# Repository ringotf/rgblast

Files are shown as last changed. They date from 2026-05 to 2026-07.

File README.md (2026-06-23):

# RGBlast - RGB + Audio To HDMI For Sega Master System & Genesis/Mega Drive

- Master System : (See "sms" branch) - Work in progress! 
- Genesis/Mega Drive : (See "md" branch)  - Work in progress! 

## Description

The original RGBlast project was a 2-bit flash analog-to-digital converter RP2040-based video capture for the Sega Mega-Drive/Genesis... which is ideal for capturing the RGB222 video signals from the Sega Master System!

This prototype has been updated so that instead of using 9 comparators (3 per RGB channel), the channels are multiplexed and switched mid-pixel for sampling so only 3 comparators are used with 3 SPDT analog switches.

## Features

- RGB222 Video Capture
- Mono Audio Capture
- HDMI output using [ikjordan PicoDVI fork](https://github.com/ikjordan/picodvi)

## To-Do

- Update schematics
- Fix wobbly vertical lines
- 50/60hz switch?
- Design PCB
- ???

## Demo Video

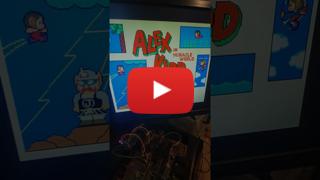
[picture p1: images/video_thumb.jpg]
[](https://youtube.com/shorts/fzoDApS1l0w)

----
----

Original Readme:

# SEGA Genesis RGBlast Processor - RP2040 code & Schematics

A hardware design for capturing RGB direct from a SEGA Genesis and delivering it via USB to a PC.

## Description

The SEGA Genesis RGBlast Processor is a Raspi Pico based video capture device that directly digitizes the RGB output of a SEGA Genesis and delivers it via USB to a host computer.

The analog channels (RGB) are captured via a 2 bit Flash ADC which is half hardware and half PIO program.

To build a functioning version from scratch, please see the circuit-schematics folder. PCB Schematics will be released if/when a proven design is achieved. Here is one of the latest prototypes as built from the schematic:



At the moment this device is capable of 6 bits per pixel, ~30FPS. Video is fairly noisy in the test PCBs which have been constructed:

https://user-images.githubusercontent.com/127321359/224463316-a748747a-c26d-4245-b84a-755739763bbe.mp4

## Getting Started

Building this to a Raspi Pico requires the C/C++ SDK: https://www.raspberrypi.com/documentation/microcontrollers/c_sdk.html

It is possible to test this device with more commonly available parts. For example utilizing LM393s as comparators (rather than the MCP6569) on a breadboard will work, but the image will be very noisy/sloppy.

You could also utilize the Raspi Pico's built-in USB (instead of the FTDI external device.) Framerates will be significantly lower.

Please see the Rust client project for the software which can receive and decode the incoming 6bpp stream to a simple application window.

## Authors

Contributors names and contact info

JP Stringham
[@jotapeh](https://mastodon.gamedev.place/@jotapeh)

## Version History

* 0.1
    * Initial Release

## License

This project is licensed under the MIT License - see the LICENSE file for details

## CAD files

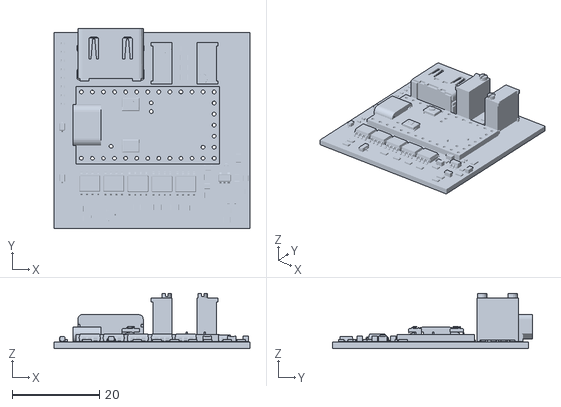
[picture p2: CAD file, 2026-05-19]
hw/rgblast-sms-test.stl
45.0 x 46.0 x 12.7

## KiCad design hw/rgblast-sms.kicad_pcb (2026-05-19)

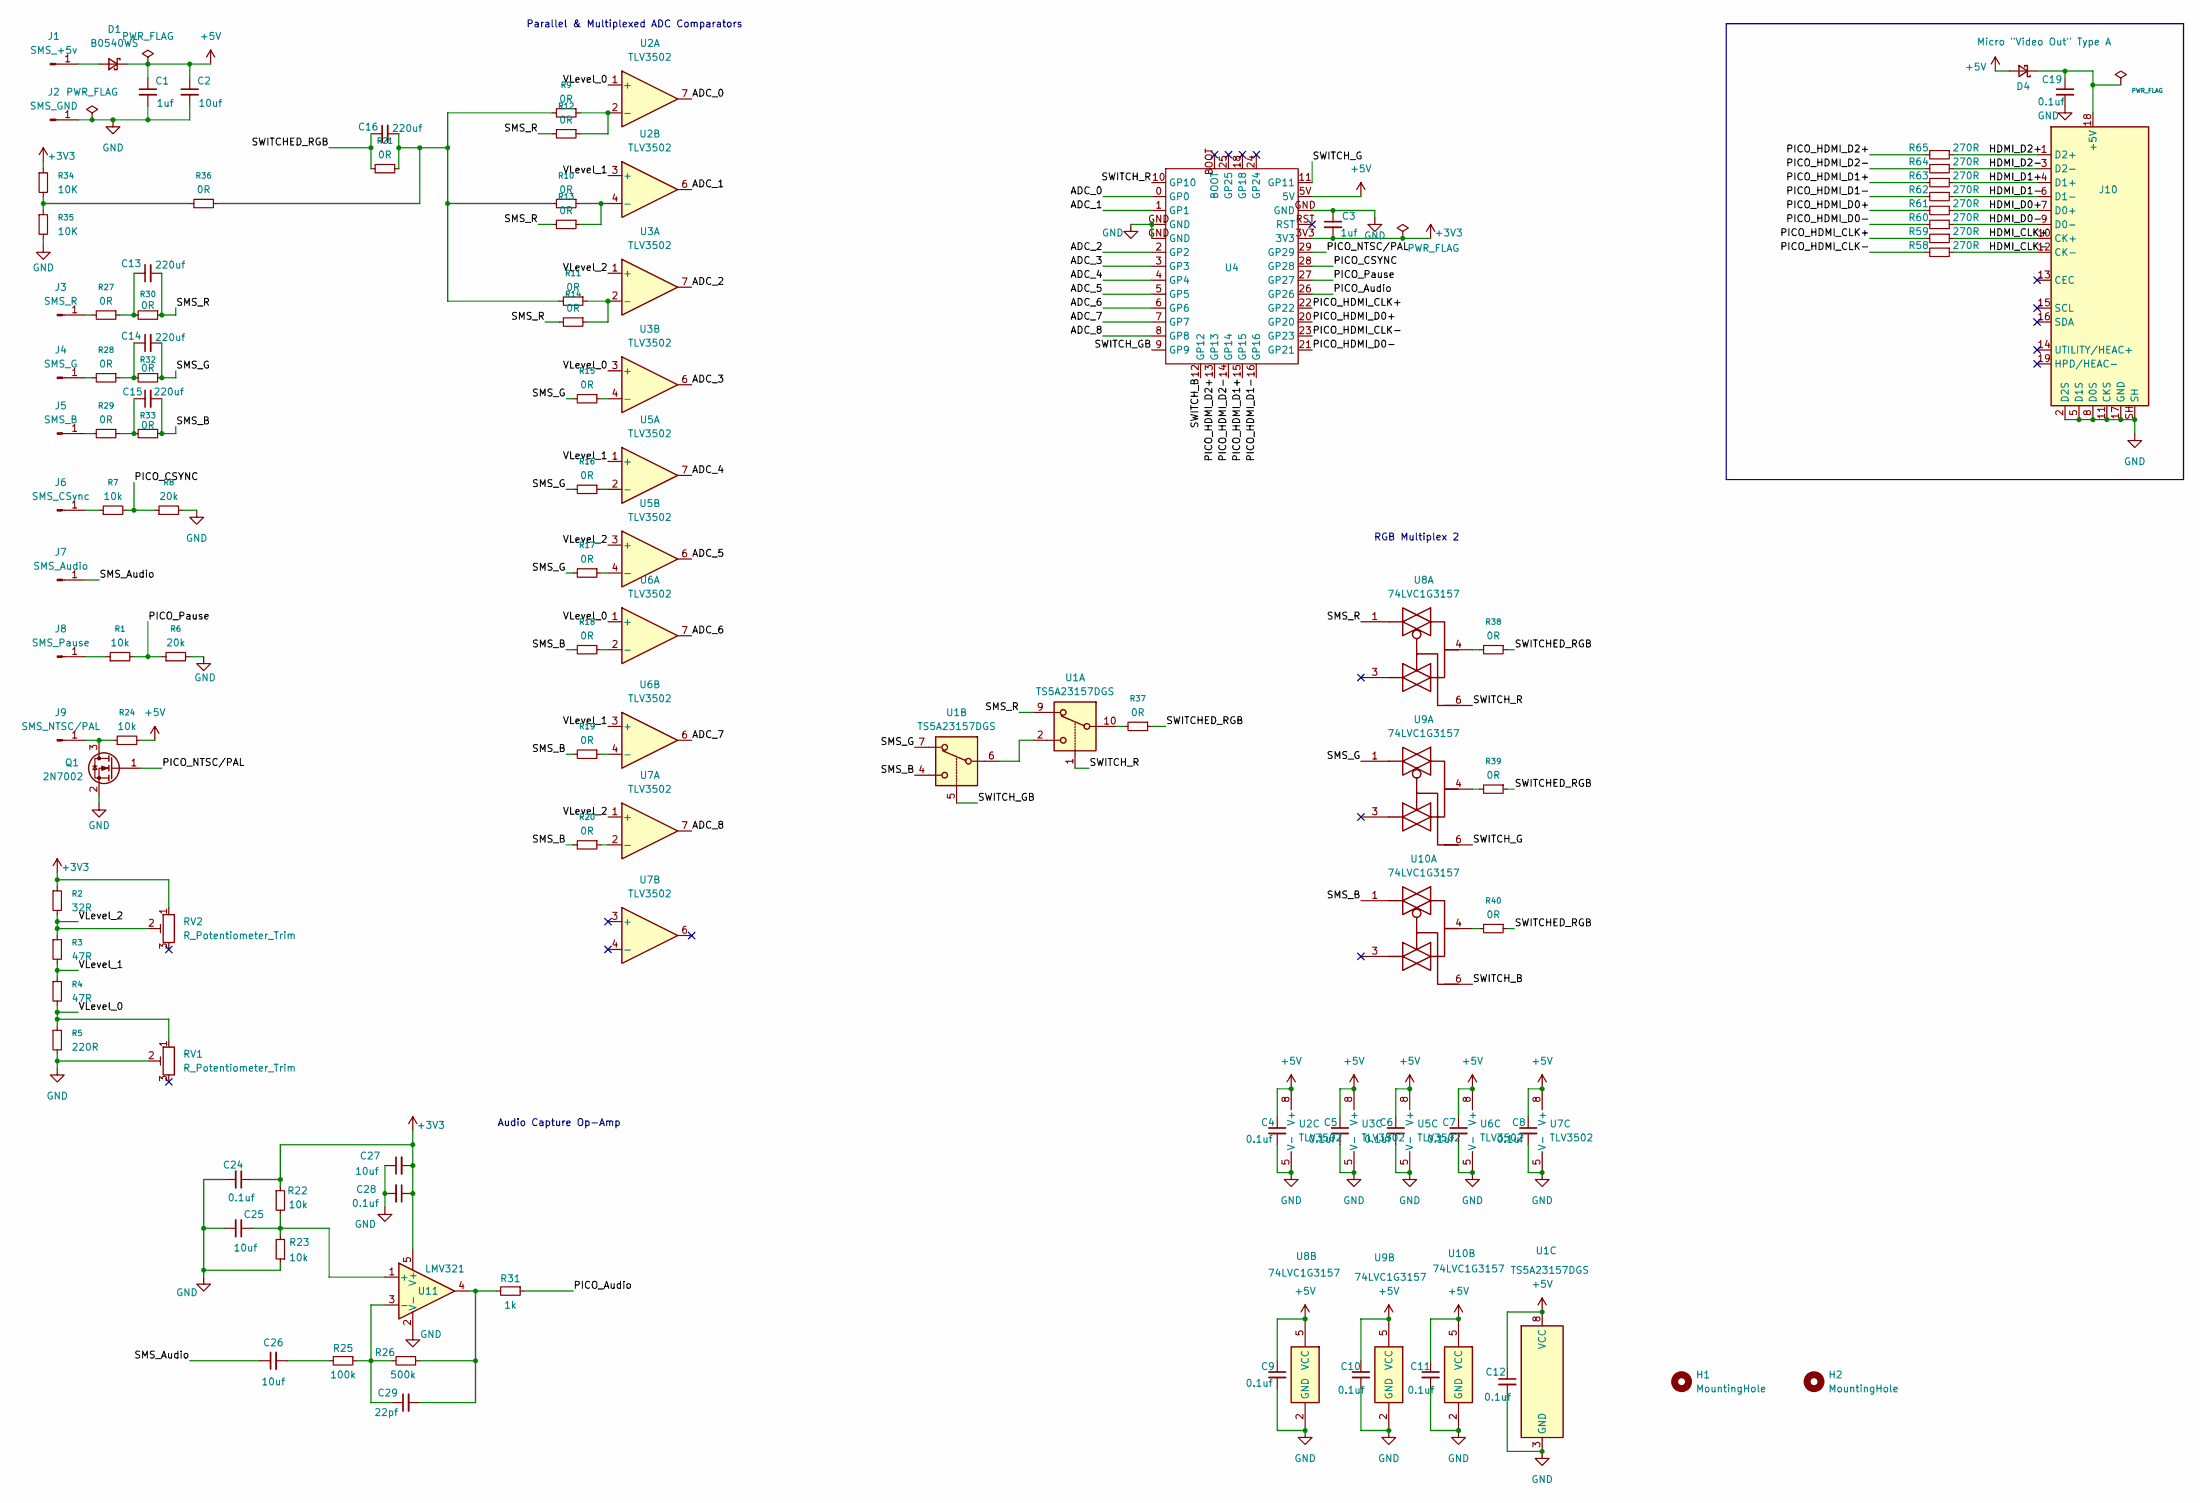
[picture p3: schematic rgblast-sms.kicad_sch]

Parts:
C1, C3: 1uf; C_0402_1005Metric_Pad0.74x0.62mm_HandSolder
C2, C27: 10uf; C_0402_1005Metric_Pad0.74x0.62mm_HandSolder
C4, C5, C6, C7, C8, C9, C10, C11, C12, C19, C28: 0.1uf; C_0402_1005Metric_Pad0.74x0.62mm_HandSolder
C13, C14, C15, C16: 220uf; C_0805_2012Metric_Pad1.18x1.45mm_HandSolder
C24: 0.1uf; C_0805_2012Metric_Pad1.18x1.45mm_HandSolder
C25, C26: 10uf; C_0805_2012Metric_Pad1.18x1.45mm_HandSolder
C29: 22pf; C_0805_2012Metric_Pad1.18x1.45mm_HandSolder
D1, D4: B0540WS; D_SOD-323_HandSoldering
H1, H2: MountingHole; ToolingHole_1.152mm
J1: SMS_+5v; TestPoint_Pad_D1.0mm
J2: SMS_GND; TestPoint_Pad_D1.0mm
J3: SMS_R; TestPoint_Pad_D1.0mm
J4: SMS_G; TestPoint_Pad_D1.0mm
J5: SMS_B; TestPoint_Pad_D1.0mm
J6: SMS_CSync; TestPoint_Pad_D1.0mm
J7: SMS_Audio; TestPoint_Pad_D1.0mm
J8: SMS_Pause; TestPoint_Pad_D1.0mm
J9: SMS_NTSC/PAL; TestPoint_Pad_D1.0mm
J10: Micro "Video Out" Type A; HDMI_A_Molex_208658-1001_Horizontal
Q1: 2N7002; SOT-23
R1, R7, R22, R23, R24: 10k; R_0805_2012Metric_Pad1.20x1.40mm_HandSolder
R2: 32R; R_0805_2012Metric_Pad1.20x1.40mm_HandSolder
R3, R4: 47R; R_0805_2012Metric_Pad1.20x1.40mm_HandSolder
R5: 220R; R_0805_2012Metric_Pad1.20x1.40mm_HandSolder
R6, R8: 20k; R_0805_2012Metric_Pad1.20x1.40mm_HandSolder
R9, R10, R11, R12, R13, R14, R15, R16, R17, R18, R19, R20, R21, R27, R28, R29, R30, R32, R33, R36, R37, R38, R39, R40: 0R; R_0805_2012Metric_Pad1.20x1.40mm_HandSolder
R25: 100k; R_0805_2012Metric_Pad1.20x1.40mm_HandSolder
R26: 500k; R_0805_2012Metric_Pad1.20x1.40mm_HandSolder
R31: 1k; R_0805_2012Metric_Pad1.20x1.40mm_HandSolder
R34, R35: 10K; R_0805_2012Metric_Pad1.20x1.40mm_HandSolder
R58, R59, R60, R61, R62, R63, R64, R65: 270R; R_0402_1005Metric_Pad0.72x0.64mm_HandSolder
RV1, RV2: R_Potentiometer_Trim; Potentiometer_Bourns_3296W_Vertical
U1: TS5A23157DGS; TSSOP-10_3x3mm_P0.5mm
U2, U3, U5, U6, U7: TLV3502; SOIC-8_3.9x4.9mm_P1.27mm
U4: pro_micro_rp2040
U8, U9, U10: 74LVC1G3157; SOT-23-6_Handsoldering
U11: LMV321; SOT-23-5_HandSoldering

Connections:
+3V3: C3.2, C24.1, C27.2, C28.1, R2.1, R22.1, R34.1, RV2.1, U4.3V3, U11.5 (V+)
+5V: C1.1, C2.1, C4.1, C5.1, C6.1, C7.1, C8.1, C9.1, C10.1, C11.1, C12.1, D1.1 (K), D4.2 (A), R24.2, U1.8 (VCC), U2.8 (V+), U3.8 (V+), U4.5V, U5.8 (V+), U6.8 (V+), U7.8 (V+), U8.5 (VCC), U9.5 (VCC), U10.5 (VCC)
/ADC_0: U2.7, U4.0 (GP0)
/ADC_1: U2.6, U4.1 (GP1)
/ADC_2: U3.7, U4.2 (GP2)
/ADC_3: U3.6, U4.3 (GP3)
/ADC_4: U4.4 (GP4), U5.7
/ADC_5: U4.5 (GP5), U5.6
/ADC_6: U4.6 (GP6), U6.7
/ADC_7: U4.7 (GP7), U6.6
/ADC_8: U4.8 (GP8), U7.7
/HDMI_CLK+: J10.10 (CK+), R59.1
/HDMI_CLK-: J10.12 (CK-), R58.1
/HDMI_D0+: J10.7 (D0+), R61.1
/HDMI_D0-: J10.9 (D0-), R60.1
/HDMI_D1+: J10.4 (D1+), R63.1
/HDMI_D1-: J10.6 (D1-), R62.1
/HDMI_D2+: J10.1 (D2+), R65.1
/HDMI_D2-: J10.3 (D2-), R64.1
/PICO_Audio: R31.1, U4.26 (GP26)
/PICO_CSYNC: R7.2, R8.1, U4.28 (GP28)
/PICO_HDMI_CLK+: R59.2, U4.22 (GP22)
/PICO_HDMI_CLK-: R58.2, U4.23 (GP23)
/PICO_HDMI_D0+: R61.2, U4.20 (GP20)
/PICO_HDMI_D0-: R60.2, U4.21 (GP21)
/PICO_HDMI_D1+: R63.2, U4.15 (GP15)
/PICO_HDMI_D1-: R62.2, U4.16 (GP16)
/PICO_HDMI_D2+: R65.2, U4.13 (GP13)
/PICO_HDMI_D2-: R64.2, U4.14 (GP14)
/PICO_NTSC/PAL: Q1.1 (G), U4.29 (GP29)
/PICO_Pause: R1.2, R6.1, U4.27 (GP27)
/SMS_Audio: C26.1, J7.1 (Pin_1_1)
/SMS_B: C15.2, R18.2, R19.2, R20.2, R33.1, U1.4, U10.1
/SMS_G: C14.2, R15.2, R16.2, R17.2, R32.1, U1.7, U9.1
/SMS_R: C13.2, R12.2, R13.2, R14.2, R30.1, U1.9, U8.1
/SWITCHED_RGB: C16.1, R21.2, R37.1, R38.1, R39.1, R40.1
/SWITCH_B: U4.12 (GP12), U10.6
/SWITCH_G: U4.11 (GP11), U9.6
/SWITCH_GB: U1.5, U4.9 (GP9)
/SWITCH_R: U1.1, U4.10 (GP10), U8.6
/VLevel_0: R4.2, R5.1, RV1.1, U2.1 (+), U3.3 (+), U6.1 (+)
/VLevel_1: R3.2, R4.1, U2.3 (+), U5.1 (+), U6.3 (+)
/VLevel_2: R2.2, R3.1, RV2.2, U3.1 (+), U5.3 (+), U7.1 (+)
GND: C1.2, C2.2, C3.1, C4.2, C5.2, C6.2, C7.2, C8.2, C9.2, C10.2, C11.2, C12.2, C19.2, C24.2, C25.2, C27.1, C28.2, J2.1 (Pin_1_1), J10.2 (D2S), J10.5 (D1S), J10.8 (D0S), J10.11 (CKS), J10.17 (GND), J10.SH, Q1.2 (S), R5.2, R6.2, R8.2, R23.1, R35.2, RV1.2, U1.3 (GND), U2.5 (V-), U3.5 (V-), U4.GND, U5.5 (V-), U6.5 (V-), U7.5 (V-), U8.2 (GND), U9.2 (GND), U10.2 (GND), U11.2 (V-)
unnamed: C13.1, R27.1, R30.2
unnamed: C14.1, R28.1, R32.2
unnamed: C15.1, R29.1, R33.2
unnamed: C16.2, R9.2, R10.2, R11.2, R21.1, R36.1
unnamed: C26.2, R25.2
unnamed: C29.2, R26.1, R31.2, U11.4
unnamed: D1.2 (A), J1.1 (Pin_1_1)
unnamed: C19.1, D4.1 (K), J10.18 (+5V)
unnamed: J3.1 (Pin_1_1), R27.2
unnamed: J4.1 (Pin_1_1), R28.2
unnamed: J5.1 (Pin_1_1), R29.2
unnamed: J6.1 (Pin_1_1), R7.1
unnamed: J8.1 (Pin_1_1), R1.1
unnamed: J9.1 (Pin_1_1), Q1.3 (D), R24.1
unnamed: R34.2, R35.1, R36.2
unnamed: R37.2, U1.10
unnamed: R38.2, U8.4
unnamed: R39.2, U9.4
unnamed: R40.2, U10.4
unnamed: U1.2, U1.6
unnamed: R9.1, R12.1, U2.2 (-)
unnamed: R10.1, R13.1, U2.4 (-)
unnamed: R11.1, R14.1, U3.2 (-)
unnamed: R15.1, U3.4 (-)
unnamed: R16.1, U5.2 (-)
unnamed: R17.1, U5.4 (-)
unnamed: R18.1, U6.2 (-)
unnamed: R19.1, U6.4 (-)
unnamed: R20.1, U7.2 (-)
unnamed: C25.1, R22.2, R23.2, U11.1 (+)
unnamed: C29.1, R25.1, R26.2, U11.3 (-)

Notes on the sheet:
RGB Multiplex 2
Parallel & Multiplexed ADC Comparators
Audio Capture Op-Amp

Board: 2 copper layers, 97 parts (0 on the bottom side), 75 nets, no tracks yet.

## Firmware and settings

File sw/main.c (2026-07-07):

#include <stdio.h>
#include <string.h>

#include <stdlib.h>
#include "pico/stdlib.h"
#include "pico/multicore.h"
#include "pico/time.h"
#include "pico/flash.h"

#include "hardware/adc.h"
#include "hardware/pio.h"
#include "hardware/dma.h"
#include "hardware/vreg.h"
#include "hardware/clocks.h"
#include "hardware/flash.h"

#include "vsync_detector.pio.h"
#include "pio_6bpp_color_read.pio.h"
//#include "flash_adc.pio.h"

#include "libdvi/dvi.h"
#include "libdvi/dvi_serialiser.h"
#include "libdvi/dvi_timing.h"

#include "main.h"

/*
#include "pico/mutex.h"
static mutex_t printf_mutex;

void safe_printf(const char* format, ...)
{
    va_list args;
    va_start(args, format);
    
    mutex_enter_blocking(&printf_mutex);
    vprintf(format, args);
    //printf(format, args);
    mutex_exit(&printf_mutex);
    
    va_end(args);
}
*/


#include "pico/util/queue.h"

#define LOG_QUEUE_LENGTH 16

typedef struct {
    char msg[80];
} log_entry_t;

static queue_t log_queue;

/*
// ====================== Initialization (on Core 0) ======================
void init_logging(void) {
    queue_init(&log_queue, sizeof(log_entry_t), LOG_QUEUE_LENGTH);
}


// ====================== Safe logging from Core 1 ======================
void log_from_core1(const char* format, ...) {
    log_entry_t entry;
    va_list args;
    va_start(args, format);
    vsnprintf(entry.msg, sizeof(entry.msg), format, args);
    va_end(args);
    
    queue_try_add(&log_queue, &entry);   // non-blocking
}

// ====================== Process logs on Core 0 (in main loop) ======================
void process_logs(void) {
    log_entry_t entry;
    while (queue_try_remove(&log_queue, &entry)) {
        printf("%s", entry.msg);
        stdio_flush();        // optional but helpful
    }
}
*/

#define IMAGE_SIZE_PIXELS (pixels_in_scanline*scanlines_in_active_area)
#define PIXELS_PER_WORD 1 //5 // 5px*6bpp+2bits
#define IMAGE_SIZE_WORDS (IMAGE_SIZE_PIXELS/PIXELS_PER_WORD)
#define IMAGE_SIZE_BYTES (IMAGE_SIZE_WORDS) //(IMAGE_SIZE_WORDS*4)


PIO vidPIO = pio0;
uint sm_sync = 0;
uint sm_read = 1;
//uint sm_read_line = 2;
uint sm_read_pixel = 2; //3;


uint offset_sync_program;
uint offset_read_program;
//uint offset_read_line_program;
uint offset_read_pixel_program;

//uint32_t IMAGE_DATA[IMAGE_SIZE_WORDS+1];
unsigned char IMAGE_DATA[IMAGE_SIZE_WORDS];
unsigned char * IMAGE_DATA_ADDRESS = IMAGE_DATA;

int dma_chan_capture;
int dma_chan_reset;

int dma_chan_lookup_capture;
int dma_chan_write_capture;
int dma_chan_lookup_reset;
int dma_chan_write_reset;


bool frameReady;

//PIO adcPIO = pio0; //pio1;
//uint sm_flashadc_red = 0;

// sync reading
// const uint SYNC_OUT_PIN = 22; // this will have to be disabled with FTDI, not enough pins
const uint SYNC_IN_PIN = 27; //15;

// pixel reading
// const uint RGB_IN_STATUS_OUT_PIN = 28;  // this will have to be disabled with FTDI, not enough pins
//const uint RGB_IN_START_PIN = 6; //9; // 9 10 b, 11 12 g, 13 14 r

//const uint BLUE_ADC_IN_PIN = 27; //16; // 16, 17, 18
//const uint BLUE_ADC_OUT_PIN = 6; //9;

//const uint GREEN_ADC_IN_PIN = 20; //19; // 19, 20, 21
//const uint GREEN_ADC_OUT_PIN = 8; //11;

const uint RED_ADC_IN_PIN = 0; //26; // 26, 27, 28
//const uint RED_ADC_OUT_PIN = 10; //13;

/*
const uint RED_NOT_ENABLE_PIN = 20;
const uint GREEN_NOT_ENABLE_PIN = 21;
const uint BLUE_NOT_ENABLE_PIN = 22;
*/
const uint ADC_PIN_COUNT = 3;

const uint NTSC_PAL_PIN = 28;
const uint PAUSE_PIN = 29;



const uint SWITCH_DRAIN_PIN = 4;

const uint SWITCH_R_PIN = 9;
const uint SWITCH_GB_PIN = 10;
const uint SWITCH_G_PIN = 10;
const uint SWITCH_B_PIN = 11;




const uint USER_BTN_PIN = 24;

#define VDP_NTSC_MODE 1
#define VDP_PAL_MODE 0


//libdvi output
#define dvi_d2_pins_base 22
#define dvi_d1_pins_base 20
#define dvi_d0_pins_base 13
#define dvi_clk_pins_base 15

//
//libdvi config
//

#define dvi_pio pio1
#define dvi_tmds_sm_0 1
#define dvi_tmds_sm_1 2
#define dvi_tmds_sm_2 3

// DVDD 1.2V (1.1V seems ok too)
//#define FRAME_WIDTH 320
//#define FRAME_HEIGHT 240
#define VREG_VSEL VREG_VOLTAGE_1_20

#define DVI_TIMING dvi_timing_640x480p_60hz

struct dvi_inst dvi0;

static struct dvi_serialiser_cfg pico_sms_rgb_conf = {
	.pio = dvi_pio,
	.sm_tmds = {dvi_tmds_sm_0, dvi_tmds_sm_1, dvi_tmds_sm_2},
	.pins_tmds = {dvi_d0_pins_base, dvi_d1_pins_base, dvi_d2_pins_base},
	.pins_clk = dvi_clk_pins_base,
	.invert_diffpairs = false
};

#define DVI_DMA_IRQ DMA_IRQ_0

#define DVI_AUDIO_CTS 28000
#define DVI_AUDIO_BUFFER_SIZE 256
audio_sample_t dvi_audio_buffer[DVI_AUDIO_BUFFER_SIZE];


//
//ADC audio capture
//
#define AUDIO_SAMPLE_RATE 44100
#define AUDIO_CHANNEL_COUNT 1 //4 //2 audio + 1 brightness potentiometer, but needs to be power of 2 for dma and ring buffer to work ok 
#define AUDIO_BUFFER_BITS 8 //11
#define AUDIO_BUFFER_SIZE (1 << AUDIO_BUFFER_BITS)
//#define AUDIO_BUFFER_SIZE 1024

__attribute__((aligned((1 << AUDIO_BUFFER_BITS))))
__attribute__((section(".time_critical.ram")))
static uint16_t audio_buffer[AUDIO_BUFFER_SIZE];

static const uint32_t audio_buffer_addr = (uint32_t)audio_buffer;




__attribute__((aligned(0x8)))
 unsigned char TWO_BIT_LUT[8] = {
    0b00,
    0b01,
    0b10,
    0b10,
    0b11,
    0b11,
    0b11,
    0b11
};

__attribute__((aligned(0x8)))
 unsigned char TWO_BIT_LUT_INVERTED[8] = {

    0b11,
    0b10,
    0b01,
    0b01,
    0b00,
    0b00,
    0b00,
    0b00

};

__attribute__((aligned(0x8)))
 unsigned char ONE_BIT_LUT[8] = {
    0b00,
    0b10,
    0b10,
    0b11,
};

__attribute__((aligned(0x200)))
unsigned char SIX_BIT_LUT[512];


void generate_lut()
{
    printf("%s: Generating Lut...\n", __func__);

    for(uint16_t r = 0; r < 8; r++)
    { 
        for(uint16_t g = 0; g < 8; g++)
        {
            for(uint16_t b = 0; b < 8; b++)
            {

                uint16_t r_value = TWO_BIT_LUT[r];
                uint16_t g_value = TWO_BIT_LUT[g];
                uint16_t b_value = TWO_BIT_LUT[b];

                //uint16_t r_value = TWO_BIT_LUT_INVERTED[r];
                //uint16_t g_value = TWO_BIT_LUT_INVERTED[g];
                //uint16_t b_value = TWO_BIT_LUT_INVERTED[b];

                
                uint16_t lut_value = (r_value << 4) | (g_value << 2) | (b_value);

                uint16_t lut_index = (r * 64) + (g * 8) + b;
                SIX_BIT_LUT[lut_index] = lut_value;

                
                //printf("R: %d G: %d B: %d Index: %04X %012b, Value: %04X %06b\n", r, g, b, lut_index, lut_index, lut_value, lut_value);

            }
        }
    }

}



//
//draws a pattern of colour bars vertically with varying intensity horizontally
//fills the frame buffer which is larger than the lcd, appears clipped in the output is normal
//
void fill_framebuffer_with_test_pattern() {
	uint16_t test_divs = pixels_in_scanline / 8;	
	uint16_t row_size = scanlines_in_active_area / 3;
	uint16_t row_diff = 1;

	for(uint32_t y = 0; y < scanlines_in_active_area; y++) {
		unsigned char row_val = (y / row_size);
		row_val = row_diff * row_val;
		row_val = 3 - row_val;

		//uint16_t row_val = 15;

		for(uint32_t x = 0; x < pixels_in_scanline; x++) {
			uint32_t pixel = 0;

            pixel = 0;

			if(x < test_divs)
			{
				//white
				pixel |= row_val;
				pixel |= (row_val << 4);
				pixel |= (row_val << 2);
			}
			else if (x < test_divs * 2)
			{
				//yellow
				pixel |= (row_val << 4);
				pixel |= (row_val << 2);
				
			}
			else if (x < test_divs * 3)
			{
				//teal
				pixel |= row_val;
				pixel |= (row_val << 2);
			
			}
			else if (x < test_divs * 4)
			{
				//green
				pixel |= (row_val << 2);
			}
			else if (x < test_divs * 5)
			{
				//purple
				pixel |= row_val;
				pixel |= (row_val << 4);
			}
			else if (x < test_divs * 6)
			{
				//red
				pixel |= (row_val << 4);
			}
			else if (x < test_divs * 7)
			{
				//blue
				pixel |= row_val;
			}
			

			IMAGE_DATA[x + (y * pixels_in_scanline)]  = pixel;
			//framebuffer2[x + (y * pixels_in_scanline)]  = ~pixel;
			//framebuffer2[x + (y * pixels_in_scanline)]  = pixel;

		}
	}

	//draws an outline around the rendered portion, in theory
	/*if(gg_now)
	{
		draw_rectangle_empty(framebuffer, gg_pixel_x_offset + 45, gg_v_lines_to_skip, gg_pixel_width, gg_pixel_height, 0xFFF);
		draw_rectangle_empty(framebuffer2, gg_pixel_x_offset + 45, gg_v_lines_to_skip, gg_pixel_width, gg_pixel_height, 0xFFF);
	}
	else
	{
		draw_rectangle_empty(framebuffer, sms_pixel_x_offset, sms_v_lines_to_skip, sms_pixel_width, sms_pixel_height, 0xFFF);
		draw_rectangle_empty(framebuffer2, sms_pixel_x_offset, sms_v_lines_to_skip, sms_pixel_width, sms_pixel_height, 0xFFF);
	}*/

}


struct repeating_timer adc_timer;
struct repeating_timer dvi_audio_timer;
volatile uint16_t audio_write_pos = 0;
volatile uint16_t audio_read_pos = 0;

volatile int64_t accum_l = 0;
volatile int64_t accum_r = 0;
volatile uint16_t decimate = 0;
static int16_t prev_l = 0;

static const uint16_t audio_bias_midpoint = 2048; //ADC is 0-4095 2048 is 1.65v midpoint of 3.3v
//uint16_t audio_bias_midpoint = 1900; //1.53v
//static const int16_t audio_bias_midpoint = 1948; //1.57v
//uint16_t audio_bias_midpoint = 1775; //1.43v
//uint16_t audio_bias_midpoint = 1737; //1.40v
//uint16_t audio_bias_midpoint = 1514; //1.22v
//uint16_t audio_bias_midpoint = 1365; //1365 is midpoint of 1.1v
//uint16_t audio_bias_midpoint = 1340; //1.08v
//uint16_t audio_bias_midpoint = 1290; //1.04v
//uint16_t audio_bias_midpoint = 1240; //1.0v


int adc_dma_chan_sample = -1;
int adc_dma_chan_control = -1;

bool __not_in_flash_func(dvi_audio_timer_callback_dma)(struct repeating_timer *t)
{

	//while(true)
	{
		//get how many audio samples for the dvi buffer
		int size = get_write_size(&dvi0.audio_ring, true);
		if(size <= 0) return true;
		if(size >= DVI_AUDIO_BUFFER_SIZE)
		{
			size = DVI_AUDIO_BUFFER_SIZE;
		}

		//get where we need to write the audio sample to
		audio_sample_t *audio_ptr = get_write_pointer(&dvi0.audio_ring);
		uint32_t audio_offset = get_write_offset(&dvi0.audio_ring);
		audio_sample_t sample;

		//Should be using trans_count as write_addr is unreliable
		uint32_t current_trans_count = dma_hw->ch[adc_dma_chan_sample].transfer_count;
		uint32_t samples_written = AUDIO_BUFFER_SIZE - current_trans_count;

		audio_write_pos = samples_written - (samples_written % 2);
		
		//printf("Trans Count: %u | Buffer Size: %u | samples requested: %u | Samples Available: %d | write_pos: %u | read_pos: %u \n",
        //   current_trans_count, AUDIO_BUFFER_SIZE, size, audio_write_pos-audio_read_pos, audio_write_pos, audio_read_pos);
		//printf("Trans Count: %u | Buffer Size: %u | samples requested: %u | Samples written: %u | write_pos: %u | read_pos: %u | FIFO level: %d\n",
        //   current_trans_count, AUDIO_BUFFER_SIZE, size, samples_written, audio_write_pos, audio_read_pos, adc_fifo_get_level());
		//printf("DMA addr: 0x%08X | Samples written: %u | write_pos: %u | read_pos: %u | FIFO level: %d | Request Size: %d | Buffer Size: %d\n",
        //   current_dma_addr, samples_written, audio_write_pos, audio_read_pos, adc_fifo_get_level(), size, AUDIO_BUFFER_SIZE);
		
		for(int cnt = 0; cnt < size; cnt++)
		{
			if(audio_write_pos == audio_read_pos)
			{
				//break;
				 sample.channels[0] = 0; //silence on underrun?
				 sample.channels[1] = 0;
			}
			else 
			{				

				sample.channels[0] =  (int16_t)(audio_buffer[audio_read_pos]) - audio_bias_midpoint ;
                sample.channels[1] =  (int16_t)(audio_buffer[audio_read_pos]) - audio_bias_midpoint ; //sample.channels[0] ;    

                /*if(audio_read_pos %50 == 0)
                {
                    printf("audio_read_pos: %d, buffer: %d, sample: %d\n", audio_read_pos, audio_buffer[audio_read_pos], sample.channels[0]);
                }*/

                //increment read position
				audio_read_pos = ((audio_read_pos + 1) % AUDIO_BUFFER_SIZE);
                

				//audio_read_pos = ((audio_read_pos + 1) % AUDIO_BUFFER_SIZE);   

				//audio_read_pos = ((audio_read_pos + 1) % AUDIO_BUFFER_SIZE);         

				//audio_read_pos = ((audio_read_pos + 1) % AUDIO_BUFFER_SIZE);
		
				audio_offset = (audio_offset + 1) % (DVI_AUDIO_BUFFER_SIZE - 1);
                
			}

			*audio_ptr++ = sample;
			increase_write_pointer(&dvi0.audio_ring, 1);
			audio_ptr = get_write_pointer(&dvi0.audio_ring);

		}

	}
	
    return true;
}

/*
bool __not_in_flash_func(adc_callback_test)(struct repeating_timer *t)
{
    adc_select_input(sms_audio_pin);
    uint16_t adc_value = adc_read();
    printf("adc_value: %d\n", adc_value);
    
    return true;
}
*/
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
int main()
{
    
	vreg_set_voltage(VREG_VSEL);
	sleep_ms(10);
	set_sys_clock_khz(DVI_TIMING.bit_clk_khz, true);

	sleep_ms(100);

    //mutex_init(&printf_mutex);
    //init_logging();
    queue_init(&log_queue, sizeof(log_entry_t), LOG_QUEUE_LENGTH); //this prevents core0 crashing... for some strange reason??

	sleep_ms(100);

	//stdio_init_all();
    stdio_usb_init();
    
	sleep_ms(500);
	printf("------------\n");
	printf("RGBlast SMS\n");
	printf("------------\n");
	sleep_ms(10);

    load_config();

	sleep_ms(10);

    gpio_init(LED_PIN);
    gpio_set_dir(LED_PIN, GPIO_OUT);
    gpio_put(LED_PIN, 1);
    
    gpio_init(SWITCH_DRAIN_PIN);
    gpio_set_dir(SWITCH_DRAIN_PIN, GPIO_OUT);
    gpio_put(SWITCH_DRAIN_PIN, 0);

    gpio_init(NTSC_PAL_PIN);
    gpio_set_dir(NTSC_PAL_PIN, GPIO_OUT);

    current_ntsc = current_config.ntsc_pal_toggle;
    
    printf("%s: current_ntsc = %d \n", __func__, current_ntsc);
   // gpio_put(LED_PIN, current_ntsc);

    if(current_ntsc)
    {
        gpio_put(NTSC_PAL_PIN, VDP_NTSC_MODE);
    }
    else
    {
        gpio_put(NTSC_PAL_PIN, VDP_PAL_MODE);
    }

    gpio_init(PAUSE_PIN);
    gpio_set_pulls(PAUSE_PIN, true, false);
    gpio_set_dir(PAUSE_PIN, GPIO_IN);

/*    
    gpio_init(RED_ADC_IN_PIN);
    gpio_set_pulls(RED_ADC_IN_PIN, false, true);
    gpio_set_dir(RED_ADC_IN_PIN, GPIO_IN);

    gpio_init(RED_ADC_IN_PIN+1);
    gpio_set_pulls(RED_ADC_IN_PIN+1, false, true);
    gpio_set_dir(RED_ADC_IN_PIN+1, GPIO_IN);

    gpio_init(RED_ADC_IN_PIN+2);
    gpio_set_pulls(RED_ADC_IN_PIN+2, false, true);
    gpio_set_dir(RED_ADC_IN_PIN+2, GPIO_IN);
*/

/*
    gpio_init(USER_BTN_PIN);
    gpio_set_dir(USER_BTN_PIN, GPIO_IN);
    gpio_set_pulls(USER_BTN_PIN, true, false);
*/

    gpio_init(SYNC_IN_PIN);
    gpio_set_pulls(SYNC_IN_PIN, false, true);
    gpio_set_dir(SYNC_IN_PIN, GPIO_IN);
    gpio_set_input_hysteresis_enabled(SYNC_IN_PIN, false);


	sleep_ms(10);

    generate_lut();

    fill_framebuffer_with_test_pattern();

	sleep_ms(10);


    claim_pio_sm();
    config_pio();

    claim_dma();
    config_dma();

	sleep_ms(10);

    dma_start();
    pio_start();

    

    //pio_sm_set_enabled(adcPIO, sm_flashadc_red, true);

    //core1_main();

	sleep_ms(10);
    
	multicore_reset_core1();

    //uint32_t *stack_top = (uint32_t *)(core1_stack + sizeof(core1_stack));
    //multicore_launch_core1_with_stack(core1_main, stack_top, sizeof(core1_stack));

    //uint32_t *stack_top = (uint32_t *)(core1_stack + sizeof(core1_stack));
    //multicore_launch_core1_with_stack(core1_main, stack_top, CORE1_STACK_SIZE);
    
    //multicore_launch_core1_with_stack(core1_main, (uint32_t*)&core1_stack[CORE1_STACK_SIZE_BYTES / 4 - 1], CORE1_STACK_SIZE_BYTES);

	multicore_launch_core1(core1_main); //libdvi core


    frameReady = false;

    bool pause_pressed = false;
    bool pause_down = false;
    bool pause_up = false;
    bool pause_was_pressed = false;

    uint8_t pause_count = 0;
    uint32_t pause_timeout = 0;
    uint32_t time_now = 0;

    frameReady = true;
    gpio_put(LED_PIN, frameReady);
    uint32_t led_timer_interval = 500;
    uint32_t led_timer = led_timer_interval;

    while (1) {
        //stdio_flush();
        //process_logs();

        //gpio_put(LED_PIN, true);
        //processNextFrame();
        //busy_wait_at_least_cycles(133);
        //busy_wait_at_least_cycles(300);
        //printf("test\n");
        
        //gpio_put(SWITCH_DRAIN_PIN, !gpio_get(SWITCH_DRAIN_PIN));
        //bool csync = !gpio_get(SYNC_IN_PIN);
        //gpio_put(SWITCH_DRAIN_PIN, csync);

        //time_now = time_us_32();

	    //sleep_ms(200);
        //if(time_now > led_timer)
        if(--led_timer <= 0)
        {
            frameReady = !frameReady;
            gpio_put(LED_PIN, frameReady);
            //led_timer = time_now + (20 * 1000); //200ms
            led_timer = led_timer_interval;
        }
        //sleep_ms(2);

        
        pause_pressed = !gpio_get(PAUSE_PIN);
        //pause_pressed = !gpio_get(PAUSE_PIN) || !gpio_get(USER_BTN_PIN);
        //pause_pressed = !gpio_get(USER_BTN_PIN);

        if(pause_pressed)
        {
            
            pause_down = !pause_was_pressed;
            pause_was_pressed = true;

            pause_up = false;
            //printf("Pause Pressed?\n");

            /*if(pause_down)
            {
                //frameReady = !frameReady;
                //gpio_put(LED_PIN, frameReady);

                if(pause_timeout > 0 && pause_timeout < time_now) 
                {
                    pause_count = 0;
                    pause_timeout = 0;
                }
            
                //pause_timeout = 0;
                
                //printf("Pause Timeout!\n");
                
                if(pause_timeout == 0 || pause_timeout > time_now)
                {
                    pause_count++;

                    //printf("%s: Pause Down! %d \n",__func__, pause_count);
                    
                    if(pause_count == 1)
                    {
                        pause_timeout = time_now + (2 * 1000 * 1000);
                    } 
                    
                    if(pause_count == 2)
                    {
                        pause_count = 0;
                        pause_timeout = 0;

                        toggle_ntsc_pal_mode();
                        //gpio_put(LED_PIN, current_ntsc);
                    }
                }
            }*/

        }
        else
        {
            pause_up = pause_was_pressed;
            pause_was_pressed = false;
            
            pause_down = false;

            //printf("Pause Not Pressed?\n");

            if(pause_up)
            {

                if(pause_timeout > 0 && pause_timeout < time_now) 
                {
                    pause_count = 0;
                    pause_timeout = 0;
                }
                if(pause_timeout == 0 || pause_timeout > time_now)
                {
                    pause_count++;

                    //printf("%s: Pause Up! %d \n",__func__, pause_count);
                    
                    if(pause_count == 1)
                    {
                        pause_timeout = time_now + (2 * 1000 * 1000);
                    } 
                    
                    if(pause_count == 4)
                    {
                        pause_count = 0;
                        pause_timeout = 0;

                        //commented out for testing as this seems to crash this core???
                        toggle_ntsc_pal_mode();

                        //gpio_put(LED_PIN, current_ntsc);
                    }
                }
            }

        }

        /*else if(pause_timeout > 0 && pause_timeout < time_now)
        {
            pause_timeout = 0;
            pause_count = 0;
            
            //printf("Pause Timeout!\n");
        }*/

        
        //printf("?");

        sleep_ms(1);
    
    }

    return 0;
}

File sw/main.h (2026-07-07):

#pragma once


#define sms_clock_pal_khz 53203.0f
#define sms_clock_ntsc_khz 53693.0f

#ifdef VIDEO_MODE_NTSC
#define sms_clock_khz sms_clock_ntsc_khz
#endif
#ifdef VIDEO_MODE_PAL
#define sms_clock_khz sms_clock_pal_khz
#endif
#ifdef VIDEO_MODE_PAL60
#define sms_clock_khz sms_clock_pal_khz
#endif

#define pixels_in_scanline 300 //250 //256 


#define sms_v_lines_to_skip_pal 45 //8 //89
#define sms_v_lines_to_skip_ntsc 18 //"ntsc" mode on a pal sms???

#ifdef VIDEO_MODE_NTSC
#define sms_v_lines_to_skip sms_v_lines_to_skip_ntsc
#endif
#ifdef VIDEO_MODE_PAL
#define sms_v_lines_to_skip sms_v_lines_to_skip_pal
#endif
#ifdef VIDEO_MODE_PAL60
#define sms_v_lines_to_skip sms_v_lines_to_skip_ntsc
#endif

#define sms_pixel_width 256 //256 //256
#define sms_pixel_height 192 //190 //192
//#define sms_pixel_x_offset 370 
#define sms_pixel_x_offset_dvi 37 



#define scanlines_in_active_area  (sms_pixel_height + sms_v_lines_to_skip + 24) //300 //190 //193  


#ifndef DVI_VERTICAL_REPEAT_SMS
#define DVI_VERTICAL_REPEAT_SMS 2
#endif



//#define LED_PIN  25 //PICO_DEFAULT_LED_PIN


//adc audio capture
#define sms_audio_pin 26



typedef struct {
    uint32_t identifier;
    uint32_t version;
    uint32_t ntsc_pal_toggle;
} Config;

//extern const uint8_t __flash_config_start[];

#define FLASH_CONFIG_OFFSET (1024 * 1024)

//#define FLASH_CONFIG_OFFSET ((uint32_t)__flash_config_start - XIP_BASE)
#define CONFIG_IDENTIFIER 0x52474253 //ASCII "RGBS"
#define CONFIG_VERSION 0x01

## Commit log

2026-05-02 Added libdvi for "dvi" video output with audio.
    Added audio capture.
    Added DMA with lookup table to write directly to framebuffer from PIO reading all 9 flash ADC inputs.
    Renamed project and source files.
2026-05-05 Corrected pixel capture timing to fix wobbly vertical lines.
    Added PAL60 video config to use PAL timing with NTSC resolution.
    [dvi.c, main.c, main.h]
2026-05-07 50/60hz switching works with 4 quick presses of pause button and config saved after each change.
    restarting pio/dma after the change to reconfigure doesnt work - breaks audio, probably breaking interrupts, as does enabling stdio_init_all()
2026-05-19 Added some docs and started updating kicad project.
    [rgblast-sms-test.stl, rgblast-sms.kicad_pcb, rgblast-sms.kicad_sch]
2026-06-07 Tweaked pixel read timing for use with TS5A23157 analog switches for multiplexed rgb.
    Tried fixing issues with core 0 crashing after startup - still weird things happening though.
    [main.c, main.h]
2026-06-08 Timings and sideset pins for SN74LVC1G3157 analog switches for multiplexed rgb
2026-07-07 Tweaked sms timings.
    Added pull down and disabled hysteresis on csync.
    Added gnd clamp during hsync, but currently disabled.
